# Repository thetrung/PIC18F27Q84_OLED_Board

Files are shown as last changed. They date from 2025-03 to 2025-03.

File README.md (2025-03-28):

PIC18F27Q84 OLED Playboard
==============================
Nothing much to say, just for entertainment & satisfy myself for designing things in my head.

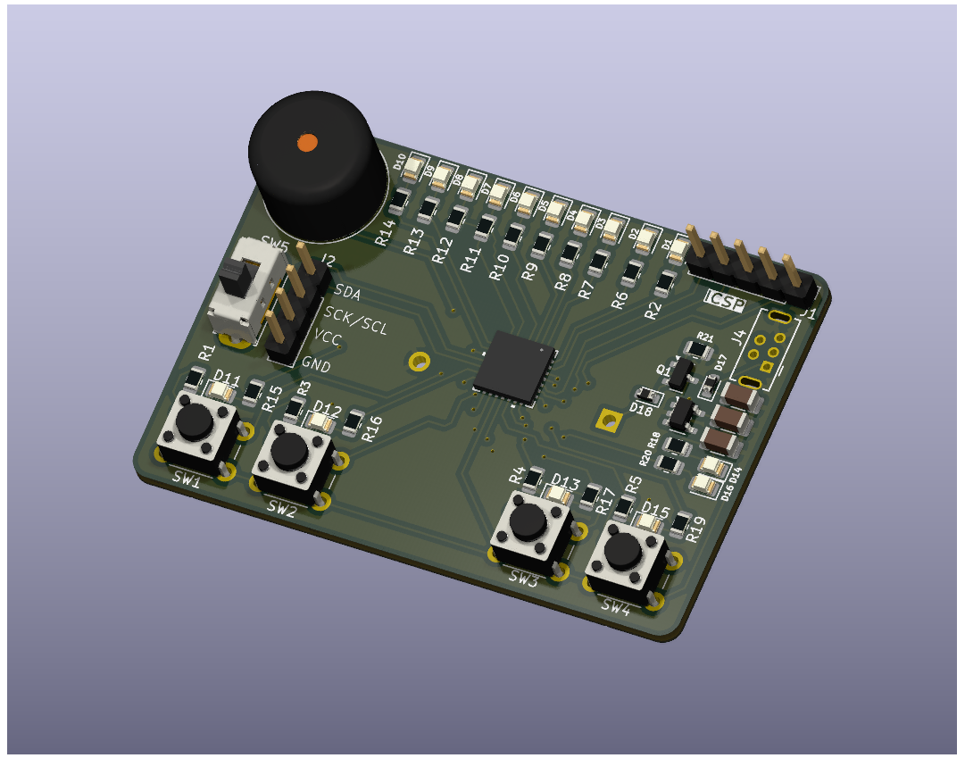
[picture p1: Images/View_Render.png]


### Overview ::
**MCU SPECS:** 64Mhz - 128KB Flash - 8KB SRAM - 1KB EEPROM. 
Detailed information on [Microchip](https://www.microchip.com/en-us/product/pic18f27q43).

The board was made with intention to resemble tiny game consoles with proper input / output, which I got inspired by ATTiny85 board. It has :

- 1x Speaker
- 1x Power slide.
- 4x Buttons Input.
- 10x LEDs on Top Row.
- 4x LEDs above all buttons.
- 1x LEDs to indicate power state.
- 1x LED for STATUS (anything you want).
- ICSP to Program with Microchip PICKIT 3/4/5.
- OLED 128x32 Module support pins (SDA/SCK/VCC/GND).
  
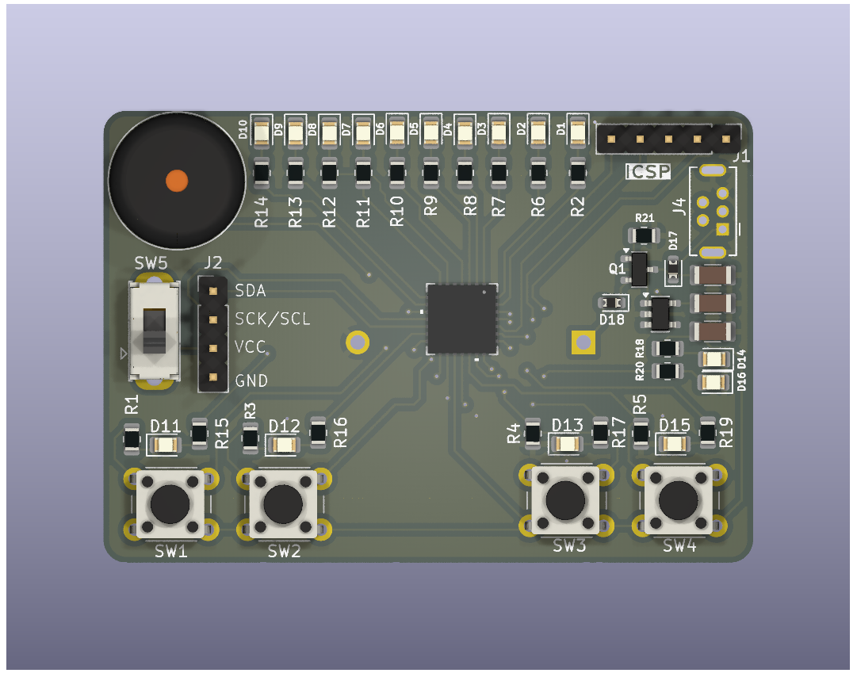
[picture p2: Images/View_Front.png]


- The 3V Battery Holder can be installed on the back. Although I'm not sure if it can actually run since got nothing to test but any compatible coin-battery should work somehow (CR2032, LIR2032... but I aim for CR2450). Turn off any unused / unnecessary modules inside your PIC & outside the board to save power on battery. I only tested this dual power system via simulator mostly :
  
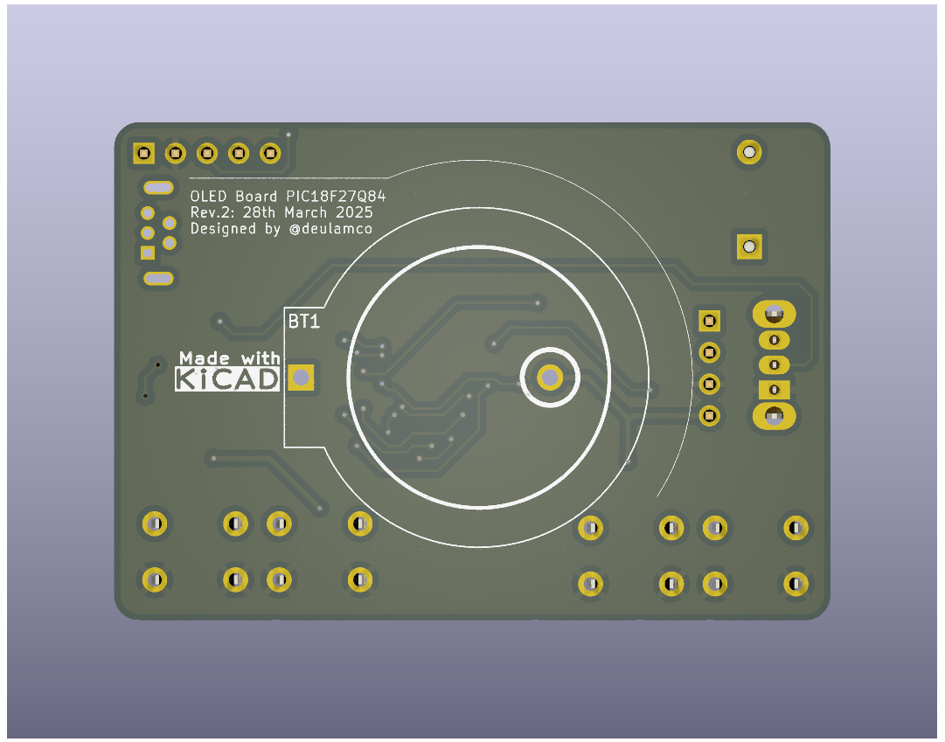
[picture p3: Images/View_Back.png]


### Schematic ::

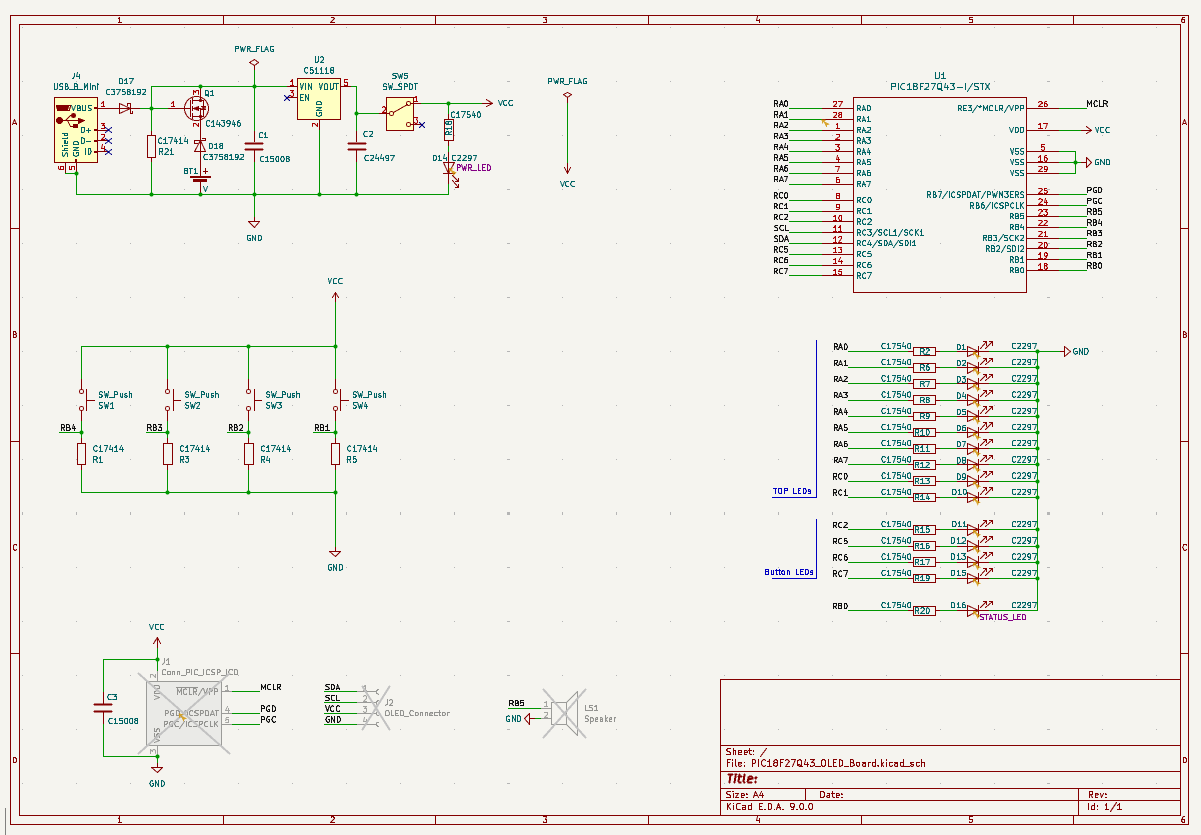
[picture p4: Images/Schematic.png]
Schematic


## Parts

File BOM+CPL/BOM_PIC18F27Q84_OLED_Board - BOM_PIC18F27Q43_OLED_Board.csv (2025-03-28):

Comment | Designator | Footprint | LCSC Part Number
200Ω | R6,R9,R11,R19,R15,R20,R17,R10,R14,R2,R12,R18,R7,R16,R13,R8 | R_0805_2012Metric | C17540
10kΩ | R21,R4,R5,R1,R3 | R_0805_2012Metric | C17414
Emerald 0805 LED | D2,D8,D1,D5,D11,D10,D16,D3,D9,D6,D15,D12,D14,D4,D13,D7 | LED_0805_2012Metric | C2297
PIC18F27Q84-I/SN | U1 | VQFN28_5N_MCH-L | C3220184
100uF | C1,C3 | C_1206_3216Metric | C15008
40V 1A 550mV@700mA 0603 Schottky Diodes | D18,D17 | D_0603_1608Metric | C3758192
20V 6.3A 21mΩ@4.5V,6.3A 1.3W 900mV 1 N-channel SOT-23 MOSFETs ROHS | Q1 | SOT-23 | C143946
LDO 65dB@(1kHz) 600mA Fixed 3.3V Positive electrode 6V SOT-25-5 Voltage Regulators | U2 | SOT-23-5 | C51118
100nF | C2 | C_1206_3216Metric | C24497

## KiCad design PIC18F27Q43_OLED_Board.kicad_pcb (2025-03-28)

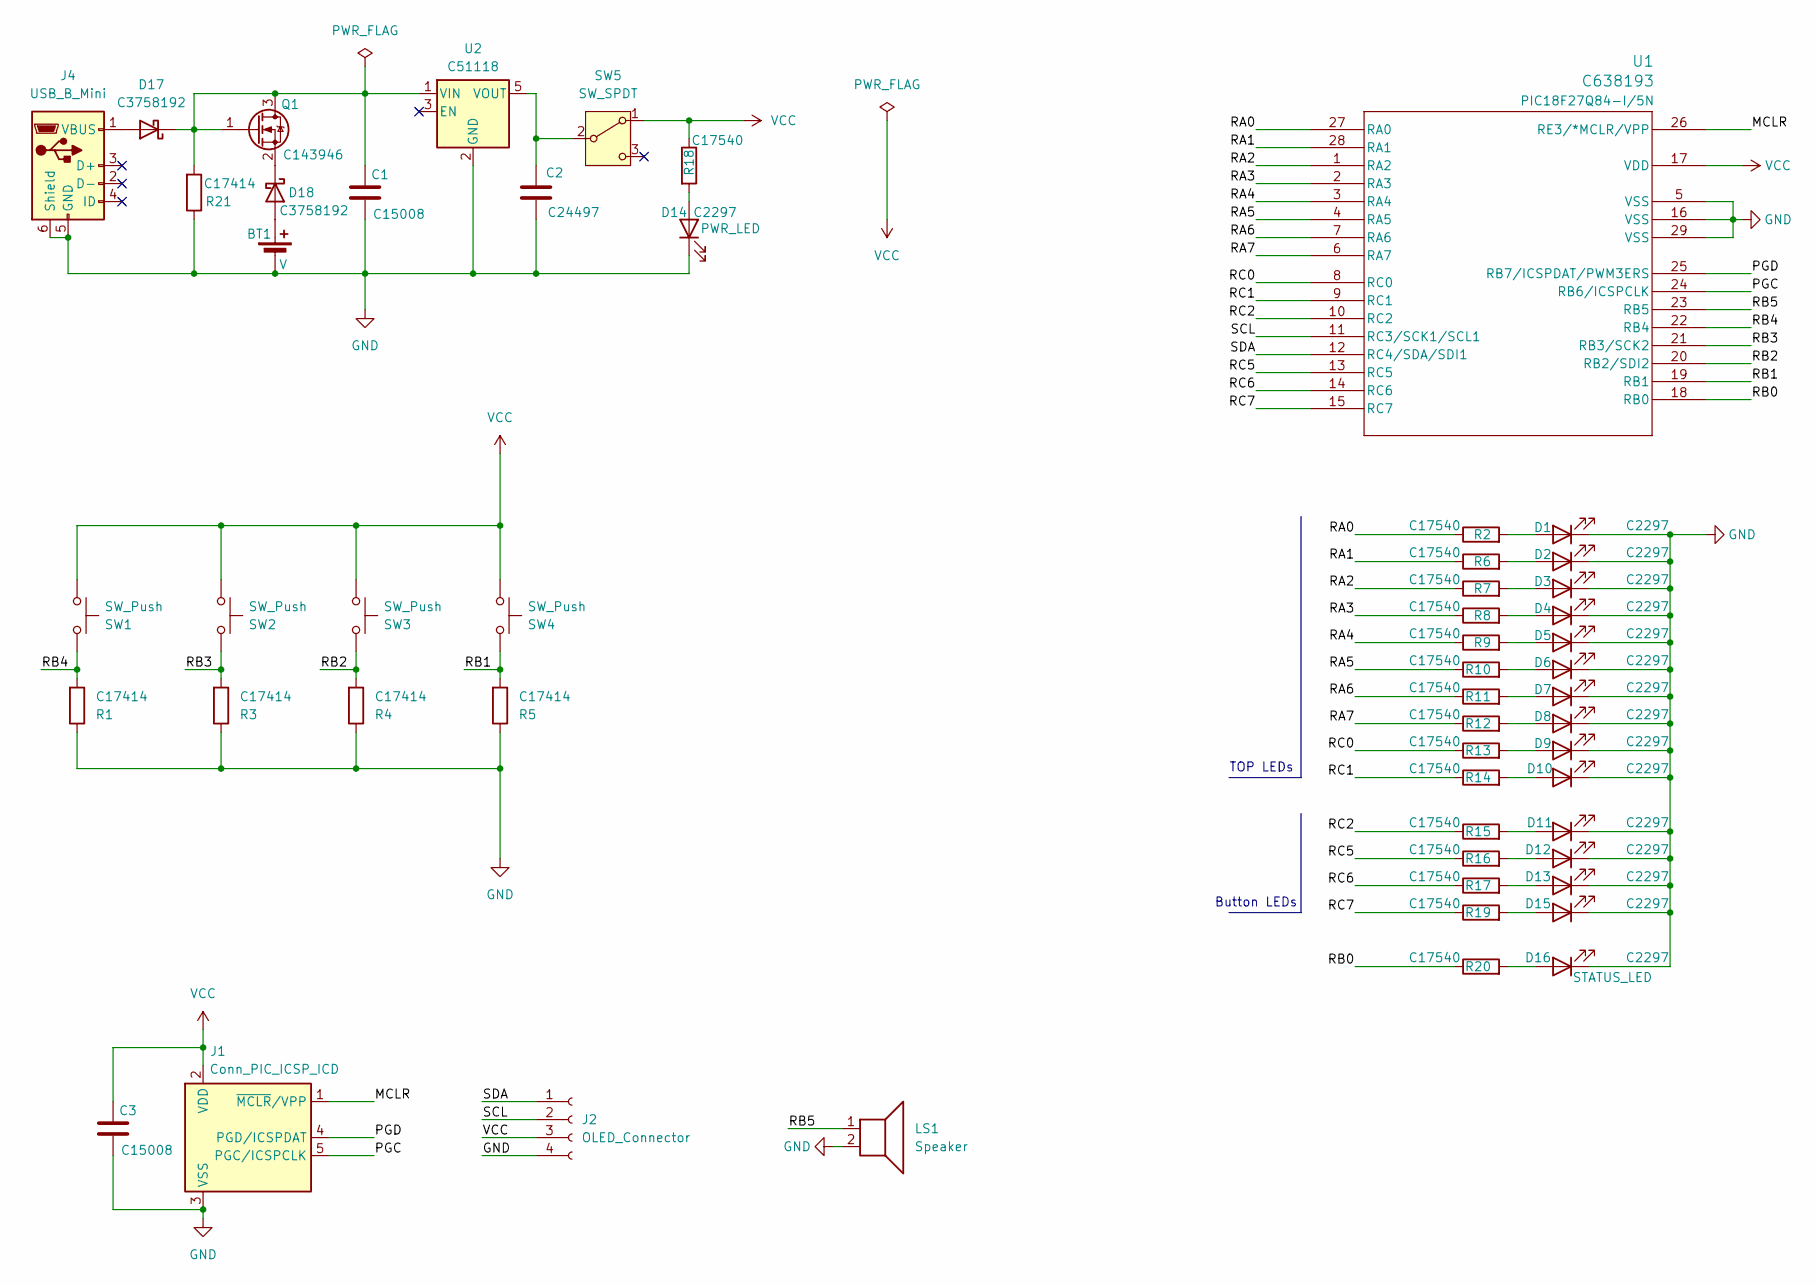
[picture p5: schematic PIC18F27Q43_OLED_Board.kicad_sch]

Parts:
BT1: V; BatteryHolder_ComfortableElectronic_CH273-2450_1x2450
C1, C3: C15008; C_1206_3216Metric
C2: C24497; C_1206_3216Metric
D1, D2, D3, D4, D5, D6, D7, D8, D9, D10, D11, D12, D13, D14, D15, D16: C2297; LED_0805_2012Metric
D17, D18: C3758192; D_0603_1608Metric
J1: Conn_PIC_ICSP_ICD; PinHeader_1x05_P2.54mm_Vertical
J2: OLED_Connector; PinHeader_1x04_P2.54mm_Vertical
J4: USB_B_Mini; USB_Mini-B_Tensility_54-00023_Vertical
LS1: Speaker; Buzzer_12x9.5RM7.6
Q1: C143946; SOT-23
R1, R3, R4, R5, R21: C17414; R_0805_2012Metric
R2, R6, R7, R8, R9, R10, R11, R12, R13, R14, R15, R16, R17, R18, R19, R20: C17540; R_0805_2012Metric
SW1, SW2, SW3, SW4: SW_Push; SW_PUSH_6mm_H5mm
SW5: SW_SPDT; SW_Slide_SPDT_Straight_CK_OS102011MS2Q
U1: C638193; VQFN28_5N_MCH
U2: C51118; SOT-23-5

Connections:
/MCLR: J1.1 (~MCLR/VPP), U1.26 (RE3/*MCLR/VPP)
/PGC: J1.5 (PGC/ICSPCLK), U1.24 (RB6/ICSPCLK)
/PGD: J1.4 (PGD/ICSPDAT), U1.25 (RB7/ICSPDAT/PWM3ERS)
/RA0: R2.1, U1.27 (RA0)
/RA1: R6.1, U1.28 (RA1)
/RA2: R7.1, U1.1 (RA2)
/RA3: R8.1, U1.2 (RA3)
/RA4: R9.1, U1.3 (RA4)
/RA5: R10.1, U1.4 (RA5)
/RA6: R11.1, U1.7 (RA6)
/RA7: R12.1, U1.6 (RA7)
/RB0: R20.1, U1.18 (RB0)
/RB1: R5.2, SW4.1, U1.19 (RB1)
/RB2: R4.2, SW3.1, U1.20 (RB2/SDI2)
/RB3: R3.2, SW2.1, U1.21 (RB3/SCK2)
/RB4: R1.2, SW1.1, U1.22 (RB4)
/RB5: LS1.1, U1.23 (RB5)
/RC0: R13.1, U1.8 (RC0)
/RC1: R14.1, U1.9 (RC1)
/RC2: R15.1, U1.10 (RC2)
/RC5: R16.1, U1.13 (RC5)
/RC6: R17.1, U1.14 (RC6)
/RC7: R19.1, U1.15 (RC7)
/SCL: J2.2, U1.11 (RC3/SCL1/SCK1)
/SDA: J2.1, U1.12 (RC4/SDA/SDI1)
GND: BT1.2 (-), C1.2, C2.2, C3.2, D1.1 (K), D2.1 (K), D3.1 (K), D4.1 (K), D5.1 (K), D6.1 (K), D7.1 (K), D8.1 (K), D9.1 (K), D10.1 (K), D11.1 (K), D12.1 (K), D13.1 (K), D14.1 (K), D15.1 (K), D16.1 (K), J1.3 (VSS), J2.4, J4.5 (GND), J4.6 (Shield), LS1.2, R1.1, R3.1, R4.1, R5.1, R21.1, U1.5 (VSS), U1.16 (VSS), U1.29 (VSS), U2.2 (GND)
unnamed: BT1.1 (+), D18.2 (A)
unnamed: D1.2 (A), R2.2
unnamed: D2.2 (A), R6.2
unnamed: D3.2 (A), R7.2
unnamed: D4.2 (A), R8.2
unnamed: D5.2 (A), R9.2
unnamed: D6.2 (A), R10.2
unnamed: D7.2 (A), R11.2
unnamed: D8.2 (A), R12.2
unnamed: D9.2 (A), R13.2
unnamed: D10.2 (A), R14.2
unnamed: D11.2 (A), R15.2
unnamed: D12.2 (A), R16.2
unnamed: D13.2 (A), R17.2
unnamed: D14.2 (A), R18.2
unnamed: D15.2 (A), R19.2
unnamed: D16.2 (A), R20.2
unnamed: D17.2 (A), J4.1 (VBUS)
unnamed: C1.1, D17.1 (K), Q1.1 (G), Q1.3 (D), R21.2, U2.1 (VIN)
unnamed: D18.1 (K), Q1.2 (S)
unnamed: C2.1, SW5.2 (B), U2.5 (VOUT)
VCC: C3.1, J1.2 (VDD), J2.3, R18.1, SW1.2, SW2.2, SW3.2, SW4.2, SW5.1 (A), U1.17 (VDD)

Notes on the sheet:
TOP LEDs
Button LEDs

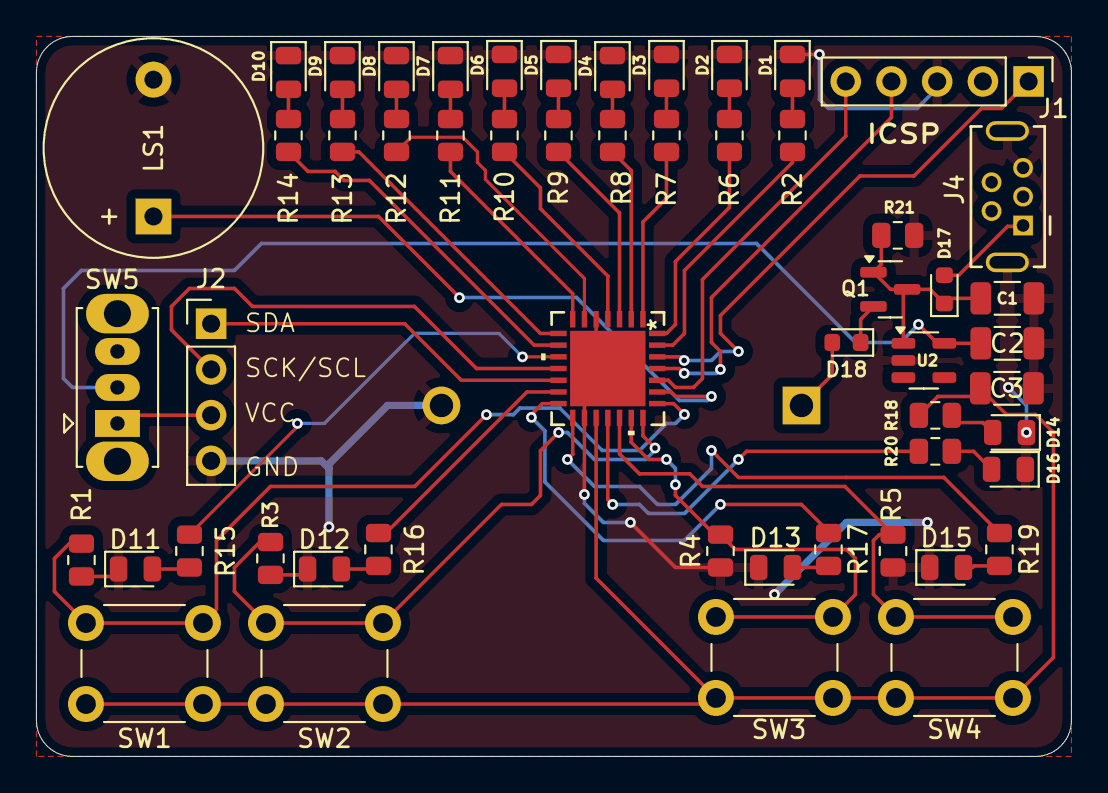
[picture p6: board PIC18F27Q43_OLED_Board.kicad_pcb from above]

Board: 2 copper layers, 57.5 x 40.0 mm, 55 parts (1 on the bottom side), 48 nets.

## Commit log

2025-03-27 Init Board
    [PIC18F27Q43_OLED_Board.kicad_pcb, PIC18F27Q43_OLED_Board.kicad_sch]
2025-03-27 Finished SCHfor VEXT + VBAT
    [PIC18F27Q43_OLED_Board.kicad_pcb, PIC18F27Q43_OLED_Board.kicad_sch]
2025-03-27 Rev.1 : PCB Design finished.
    [PIC18F27Q43_OLED_Board.kicad_pcb]
2025-03-27 Refine Silkscreen
    [PIC18F27Q43_OLED_Board.kicad_pcb, PIC18F27Q43_OLED_Board.kicad_sch]
2025-03-28 Ready for PCBA
    [BOM_PIC18F27Q43_OLED_Board.csv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]
2025-03-28 move from Q43 -> Q84 due to chip shortage
    [BOM_PIC18F27Q43_OLED_Board - BOM_PIC18F27Q43_OLED_Board.csv, BOM_PIC18F27Q43_OLED_Board.csv, PIC18F27Q43_OLED_Board.kicad_pcb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]
2025-03-28 Finished Routing to new Q84
    [PIC18F27Q43_OLED_Board.kicad_pcb]
2025-03-28 Corrected BOM+CPL & Updated Images
    [BOM_PIC18F27Q84_OLED_Board - BOM_PIC18F27Q43_OLED_Board.csv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]
2025-04-02 update symbol
    [PIC18F27Q43_OLED_Board.kicad_sch]
